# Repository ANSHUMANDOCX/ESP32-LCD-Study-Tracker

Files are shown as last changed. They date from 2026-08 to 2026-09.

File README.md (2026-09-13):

# ESP32-LCD-Study-Tracker
Its a Compact Server based study tracker using a OLED display and a ESP32 that help one track their study/work time on particular subjects and also lets use set a target using the interactive web page hosted on the ESP

# Parts used 
- Esp32 Wroom
- 1602 LCD Display
- PCB with onboard programmer

# Why i made this 
This device is made to solve one of the problems i face while studying i keep on getting distracted while i do something and using this device i will be able to keep track of my productive hours so i can get a reality check on long i think i am productive vs how long i actually am !!. 
# Features
- The system uses Display to set timer and keep track of your productive hours. It also has a webpage hosted on the ESP that helps you check on the hours spent at a glance. Also one can set target for the day how much time one needs to be productive for.
- It also has a Log system that logs the time we have spent on something and helps us keep track of how productive one has been. It also has a option to download the log all together as a csv file.
- There is a header for Connecting the LCD using I2C
- There are 3 Buttons for controlling the Display 'Start' , 'Stop' and , 'Change'.
- We can long press the STOP button to turnoff the backlight of the lcd since it could be distracting for some of us.

# Programming
The code is very simple you will need to import the project in platform io and once flash the system image to load the website on the ESP and next upload the main.c file thats it. Also the subject/ Topic one needs to focus on is under a placeholder so anyone can change it according to their needs.  

# PCB and Schematic and CAD





## Build 
https://youtu.be/7US3xBiMZxA?si=RdkPRtCYgrZsQL8k
https://youtu.be/MXmio46lXlo?si=qvKTUyI2eKW5zzEd




# BOM
| Serial No | Product name | Quantity | Supplier | Price | Total | Link |
| ---: | --- | ---: | --- | ---: | ----: | --- |
| 1 | RC06
03JR-070RL        |      100 | LCSC     | $0.0034 | $0.34 | [LCSC](https://www.lcsc.com/product-detail/C95177.html)   |
|         2 | ME6217C33M5G          |        5 | LCSC     | $0.1219 | $0.61 | [LCSC](https://www.lcsc.com/product-detail/C427602.html)  |
|         3 | CH343P                |        1 | LCSC     | $1.1227 | $1.12 | [LCSC](https://www.lcsc.com/product-detail/C2846043.html) |
|         4 | ESP32-WROOM-32E-N4    |        1 | LCSC     | $3.7668 | $3.77 | [LCSC](https://www.lcsc.com/product-detail/C701341.html)  |
|         5 | TS-1088-AR02016       |       10 | LCSC     | $0.0531 | $0.53 | [LCSC](https://www.lcsc.com/product-detail/C720477.html)  |
|         6 | GT-TC060A-H025-L1S    |        5 | LCSC     | $0.0929 | $0.46 | [LCSC](https://www.lcsc.com/product-detail/C7450623.html) |
|         7 | FRC0603F2201TS        |      100 | LCSC     | $0.0022 | $0.22 | [LCSC](https://www.lcsc.com/product-detail/C2907005.html) |
|         8 | FRC0603F5101TS        |      100 | LCSC     | $0.0021 | $0.21 | [LCSC](https://www.lcsc.com/product-detail/C2907044.html) |
|         9 | RC0603FR-0710KL       |      100 | LCSC     | $0.0040 | $0.40 | [LCSC](https://www.lcsc.com/product-detail/C98220.html)   |
|        10 | CL10B104KB8NNNC       |      200 | LCSC     | $0.0118 | $2.36 | [LCSC](https://www.lcsc.com/product-detail/C1591.html)    |
|        11 | FRC0603F1001TS        |      100 | LCSC     | $0.0029 | $0.29 | [LCSC](https://www.lcsc.com/product-detail/C2907002.html) |
|        12 | SS8050                |       50 | LCSC     | $0.0100 | $0.50 | [LCSC](https://www.lcsc.com/product-detail/C916392.html)  |
|        13 | TYPE-C 16PIN 2MD(073) |       20 | LCSC     | $0.0707 | $1.41 | [LCSC](https://www.lcsc.com/product-detail/C2765186.html) |
|        14 | GRM188R60J476ME15D    |        5 | LCSC     | $0.1934 | $0.97 | [LCSC](https://www.lcsc.com/product-detail/C140782.html)  |
|        15 | CL10A475KP8NNNC       |       50 | LCSC     | $0.0199 | $1.00 | [LCSC](https://www.lcsc.com/product-detail/C1705.html)    |
|        16 | CL10B105KA8NNNC       |       10 | LCSC     | $0.0216 | $0.22 | [LCSC](https://www.lcsc.com/product-detail/C29936.html)   |
|        17 | CL10A106KP8NNNC       |       20 | LCSC     | $0.0353 | $0.71 | [LCSC](https://www.lcsc.com/product-detail/C19702.html)   |
|        18 | PCB       |       1 | JLC     | $2 | $2 | [JLC](jlcpcb.com)   |
|19|LCD Display|1|Robu|$2|$2|[Robu](https://robu.in/product/lcd1602-parallel-lcd-display-with-iic-i2c-interface/)|
||**TOTAL**||||20|||

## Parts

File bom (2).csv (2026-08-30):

Index | LCSC# | MPN | Manufacturer | Package | Customer # | Description | RoHS | Quantity | MOQ | Multiple | Unit Price($) | Extended Price($) | Product Link
1 | C95177 | RC0603JR-070RL | YAGEO | 0603 |  | 100mW 0Ω 75V Thick Film Resistor ±5% 0603 Chip Resistor - Surface Mount RoHS | yes | 100 | 100 | 100 | 0.0034 | 0.34 | https://www.lcsc.com/product-detail/C95177.html
2 | C427602 | ME6217C33M5G | MICRONE | SOT-23-5 |  | 3.3V Positive Fixed SOT-23-5 Voltage Regulators - Linear, Low Drop Out (LDO) Regulators | yes | 5 | 5 | 5 | 0.1219 | 0.61 | https://www.lcsc.com/product-detail/C427602.html
3 | C2846043 | CH343P | WCH | TQFN-16-EP(3x3) |  | USB to UART 6Mbps USB 2.0 TQFN-16-EP(3x3) Interface Controllers | yes | 1 | 1 | 1 | 1.1227 | 1.12 | https://www.lcsc.com/product-detail/C2846043.html
4 | C701341 | ESP32-WROOM-32E-N4 | ESPRESSIF | SMD,25.5x18mm |  | 2.4GHz On-board PCB Antenna -98dBm SMD,25.5x18mm RF Transceiver Modules and Modems RoHS | yes | 1 | 1 | 1 | 3.7668 | 3.77 | https://www.lcsc.com/product-detail/C701341.html
5 | C720477 | TS-1088-AR02016 | XUNPU | SMD,4x3mm |  | Tactile Switch SPST 160gf 2mm SMD (SMT) Tab 4mm x 3mm Surface Mount | yes | 10 | 10 | 10 | 0.0531 | 0.53 | https://www.lcsc.com/product-detail/C720477.html
6 | C7450623 | GT-TC060A-H025-L1S | G-Switch | SMD,6x3mm |  | Tactile Switch SPST 160gf 2.5mm SMD (SMT) Tab 6.05mm x 3.5mm Surface Mount | yes | 5 | 5 | 5 | 0.0929 | 0.46 | https://www.lcsc.com/product-detail/C7450623.html
7 | C2907005 | FRC0603F2201TS | FOJAN | 0603 |  | 2.2kΩ ±1% 100mW 0603 Thick Film Resistor | yes | 100 | 100 | 100 | 0.0022 | 0.22 | https://www.lcsc.com/product-detail/C2907005.html
8 | C2907044 | FRC0603F5101TS | FOJAN | 0603 |  | 5.1kΩ ±1% 100mW 0603 Thick Film Resistor | yes | 100 | 100 | 100 | 0.0021 | 0.21 | https://www.lcsc.com/product-detail/C2907044.html
9 | C98220 | RC0603FR-0710KL | YAGEO | 0603 |  | 100mW 10kΩ 75V Thick Film Resistor ±100ppm/℃ ±1% 0603 Chip Resistor - Surface Mount RoHS | yes | 100 | 100 | 100 | 0.0040 | 0.40 | https://www.lcsc.com/product-detail/C98220.html
10 | C1591 | CL10B104KB8NNNC | Samsung Electro-Mechanics | 0603 |  | 100nF ±10% 50V Ceramic Capacitor X7R 0603 | yes | 200 | 100 | 100 | 0.0118 | 2.36 | https://www.lcsc.com/product-detail/C1591.html
11 | C2907002 | FRC0603F1001TS | FOJAN | 0603 |  | 1kΩ ±1% 100mW 0603 Thick Film Resistor | yes | 100 | 100 | 100 | 0.0029 | 0.29 | https://www.lcsc.com/product-detail/C2907002.html
12 | C916392 | SS8050 | JSMSEMI | SOT-23 |  | Bipolar (BJT) Transistor NPN 25V 1.5A 300mW Surface Mount SOT-23 | yes | 50 | 50 | 50 | 0.0100 | 0.50 | https://www.lcsc.com/product-detail/C916392.html
13 | C2765186 | TYPE-C 16PIN 2MD(073) | SHOU HAN | SMD |  | USB-C (USB TYPE-C) Receptacle Connector 16 Position Surface Mount, Right Angle | yes | 20 | 20 | 20 | 0.0707 | 1.41 | https://www.lcsc.com/product-detail/C2765186.html
14 | C140782 | GRM188R60J476ME15D | muRata | 0603 |  | 47uF ±20% 6.3V Ceramic Capacitor X5R 0603 | yes | 5 | 5 | 5 | 0.1934 | 0.97 | https://www.lcsc.com/product-detail/C140782.html
15 | C1705 | CL10A475KP8NNNC | Samsung Electro-Mechanics | 0603 |  | 4.7uF ±10% 10V Ceramic Capacitor X5R 0603 | yes | 50 | 50 | 50 | 0.0199 | 1.00 | https://www.lcsc.com/product-detail/C1705.html
16 | C29936 | CL10B105KA8NNNC | Samsung Electro-Mechanics | 0603 |  | 1uF ±10% 25V Ceramic Capacitor X7R 0603 | yes | 10 | 10 | 10 | 0.0216 | 0.22 | https://www.lcsc.com/product-detail/C29936.html
17 | C19702 | CL10A106KP8NNNC | Samsung Electro-Mechanics | 0603 |  | 10uF ±10% 10V Ceramic Capacitor X5R 0603 | yes | 20 | 20 | 20 | 0.0353 | 0.71 | https://www.lcsc.com/product-detail/C19702.html

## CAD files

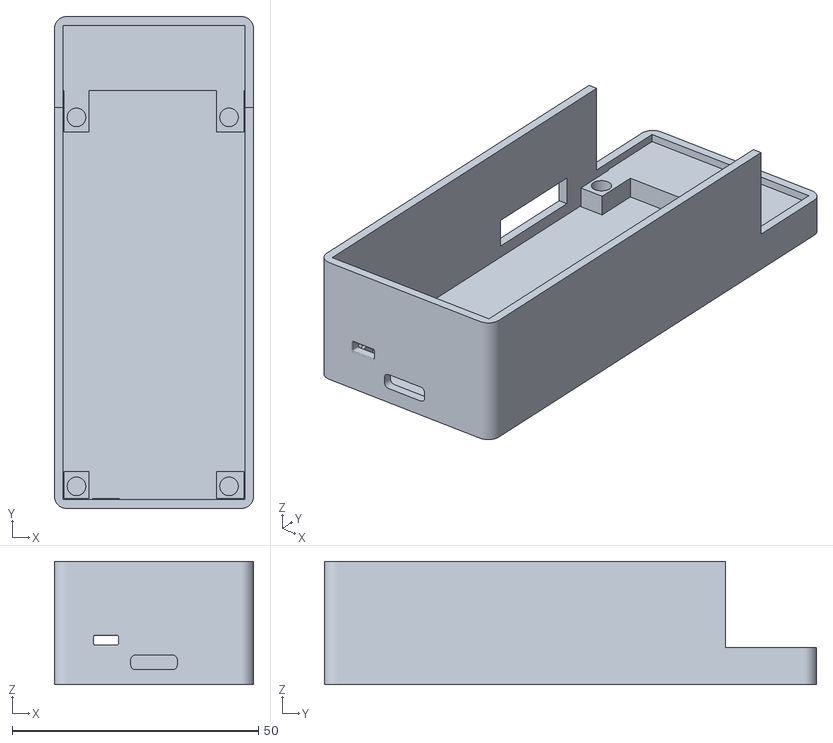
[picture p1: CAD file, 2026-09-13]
CAD/Bottom.stl
40.5 x 100.0 x 25.0

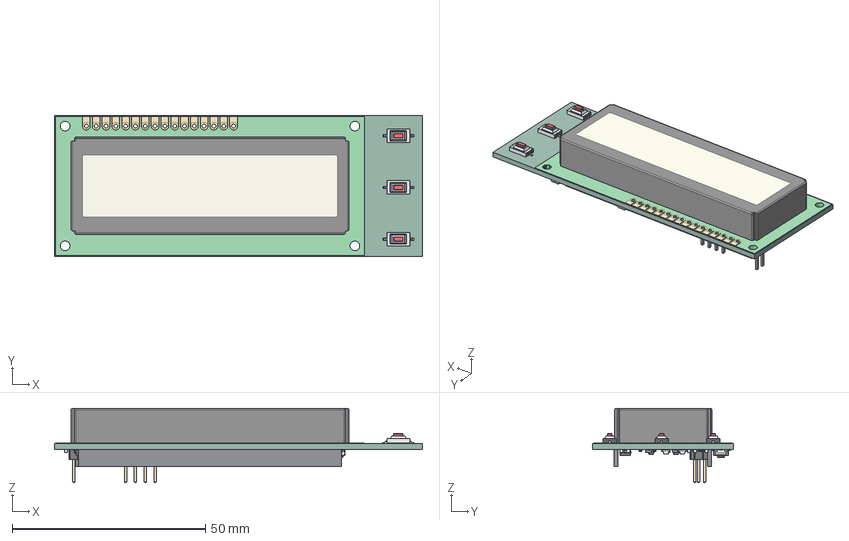
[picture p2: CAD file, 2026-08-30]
PCB/Study_Tracker.step
95.2 x 36.5 x 19.2 mm
SW_SPST_CK_RS282G05A3 x 3
WC1602A
R_0603_1608Metric x 10
PinHeader_1x04_P2.54mm_Vertical
LED_0805_2012Metric x 2
SW_Push_SPST_NO_Alps_SKRK x 2
C_0603_1608Metric x 10
SOT-23 x 2
PinHeader_1x02_P2.54mm_Vertical
SOT-23-5
Stuy Tracker org_PCB

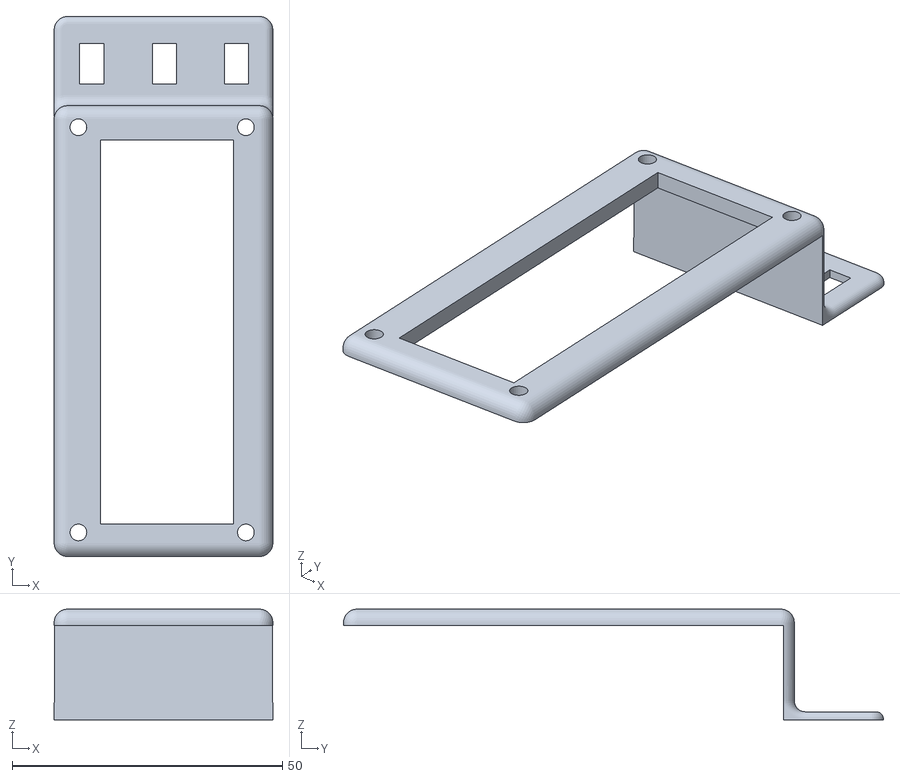
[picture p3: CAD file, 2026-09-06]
CAD/top.stl
40.5 x 100.0 x 20.5

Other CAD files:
CAD/Bottom.f3z
CAD/TOP.f3z

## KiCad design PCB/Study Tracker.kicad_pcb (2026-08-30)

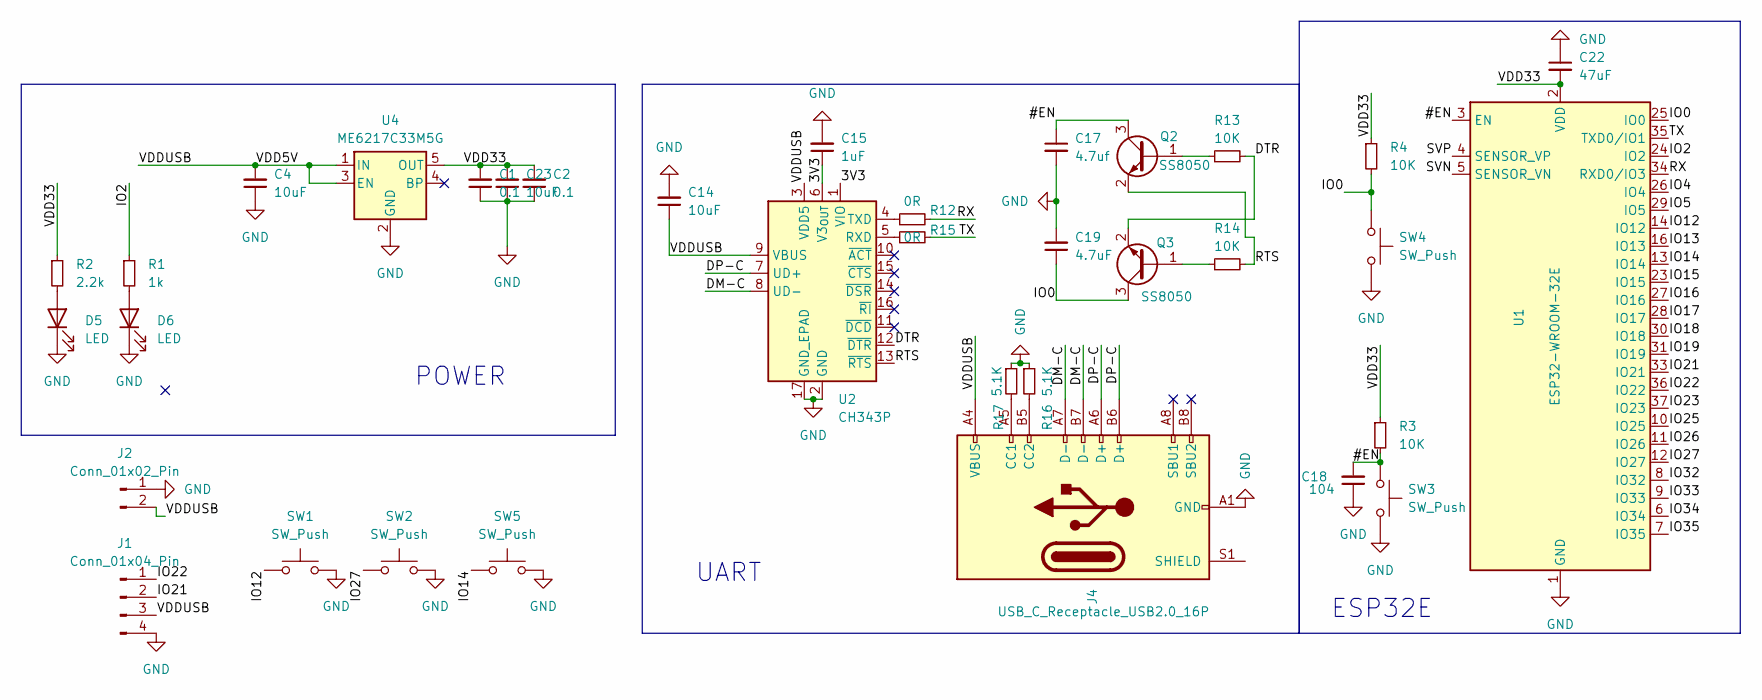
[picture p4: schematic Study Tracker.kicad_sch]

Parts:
C1, C2: 0.1; C_0603_1608Metric_Pad1.08x0.95mm_HandSolder
C4, C14, C23: 10uF; C_0603_1608Metric_Pad1.08x0.95mm_HandSolder
C15: 1uF; C_0603_1608Metric_Pad1.08x0.95mm_HandSolder
C17: 4.7uf; C_0603_1608Metric_Pad1.08x0.95mm_HandSolder
C18: 104; C_0603_1608Metric_Pad1.08x0.95mm_HandSolder
C19: 4.7uF; C_0603_1608Metric_Pad1.08x0.95mm_HandSolder
C22: 47uF; C_0603_1608Metric_Pad1.08x0.95mm_HandSolder
D5, D6: LED; LED_0805_2012Metric_Pad1.15x1.40mm_HandSolder
J1: Conn_01x04_Pin; PinHeader_1x04_P2.54mm_Vertical
J2: Conn_01x02_Pin; PinHeader_1x02_P2.54mm_Vertical
J4: USB_C_Receptacle_USB2.0_16P; USB_C_Receptacle_XKB_U262-16XN-4BVC11
Q2, Q3: SS8050; SOT-23
R1: 1k; R_0603_1608Metric_Pad0.98x0.95mm_HandSolder
R2: 2.2k; R_0603_1608Metric_Pad0.98x0.95mm_HandSolder
R3, R4, R13, R14: 10K; R_0603_1608Metric_Pad0.98x0.95mm_HandSolder
R12, R15: 0R; R_0603_1608Metric_Pad0.98x0.95mm_HandSolder
R16, R17: 5.1K; R_0603_1608Metric_Pad0.98x0.95mm_HandSolder
SW1, SW2, SW5: SW_Push; SW_SPST_CK_RS282G05A3
SW3, SW4: SW_Push; SW_Push_SPST_NO_Alps_SKRK
U1: ESP32-WROOM-32E; ESP32-WROOM-32D
U2: CH343P; WCH_QFN-16-1EP_3x3mm_P0.5mm_EP1.8x1.8mm
U4: ME6217C33M5G; SOT-23-5

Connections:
/3V3: C15.1, U2.1 (VIO), U2.6 (V3_{OUT})
/#EN: C17.1, C18.2, Q2.3 (C), R3.2, SW3.1, U1.3 (EN)
/DM-C: J4.A7 (D-), J4.B7 (D-), U2.8 (UD-)
/DP-C: J4.A6 (D+), J4.B6 (D+), U2.7 (UD+)
/DTR: Q3.2 (E), R13.2, U2.12 (~DTR)
/IO0: C19.1, Q3.3 (C), R4.2, SW4.1, U1.25 (IO0)
/IO2: R1.1, U1.24 (IO2)
/IO4: U1.26 (IO4)
/IO5: U1.29 (IO5)
/IO12: SW1.1, U1.14 (IO12)
/IO13: U1.16 (IO13)
/IO14: SW5.1, U1.13 (IO14)
/IO15: U1.23 (IO15); also elsewhere on the board
/IO16: U1.27 (IO16); also elsewhere on the board
/IO17: U1.28 (IO17); also elsewhere on the board
/IO18: U1.30 (IO18); also elsewhere on the board
/IO19: U1.31 (IO19); also elsewhere on the board
/IO21: J1.2, U1.33 (IO21)
/IO22: J1.1, U1.36 (IO22)
/IO23: U1.37 (IO23); also elsewhere on the board
/IO25: U1.10 (IO25)
/IO26: U1.11 (IO26)
/IO27: SW2.1, U1.12 (IO27)
/IO32: U1.8 (IO32)
/IO33: U1.9 (IO33)
/IO34: U1.6 (IO34)
/IO35: U1.7 (IO35)
/RTS: Q2.2 (E), R14.2, U2.13 (~RTS)
/RX: R12.2, U1.34 (RXD0/IO3)
/SVN: U1.5 (SENSOR_VN)
/SVP: U1.4 (SENSOR_VP)
/TX: R15.2, U1.35 (TXD0/IO1)
/VDD5V: C4.2, C14.1, J1.3, J2.2, J4.A4 (VBUS), J4.A9 (VBUS), J4.B4 (VBUS), J4.B9 (VBUS), U2.3 (VDD5), U2.9 (VBUS), U4.1 (IN), U4.3 (EN); also elsewhere on the board
/VDD33: C1.2, C2.2, C22.2, C23.2, R2.1, R3.1, R4.1, U1.2 (VDD), U4.5 (OUT)
GND: C1.1, C2.1, C4.1, C14.2, C15.2, C17.2, C18.1, C19.2, C22.1, C23.1, D5.1 (K), D6.1 (K), J1.4, J2.1, J4.A1 (GND), J4.A12 (GND), J4.B1 (GND), J4.B12 (GND), R16.1, R17.1, SW1.2, SW2.2, SW3.2, SW4.2, SW5.2, U1.1 (GND), U1.15 (GND), U1.38 (GND), U1.39 (GND), U2.2 (GND), U2.17 (GND_EPAD), U4.2 (GND); also elsewhere on the board
unnamed: D5.2 (A), R2.2
unnamed: D6.2 (A), R1.2
unnamed: J4.A5 (CC1), R17.2
unnamed: J4.B5 (CC2), R16.2
unnamed: Q2.1 (B), R13.1
unnamed: Q3.1 (B), R14.1
unnamed: R15.1, U2.5 (RXD)
unnamed: R12.1, U2.4 (TXD)

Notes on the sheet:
UART
POWER
ESP32E

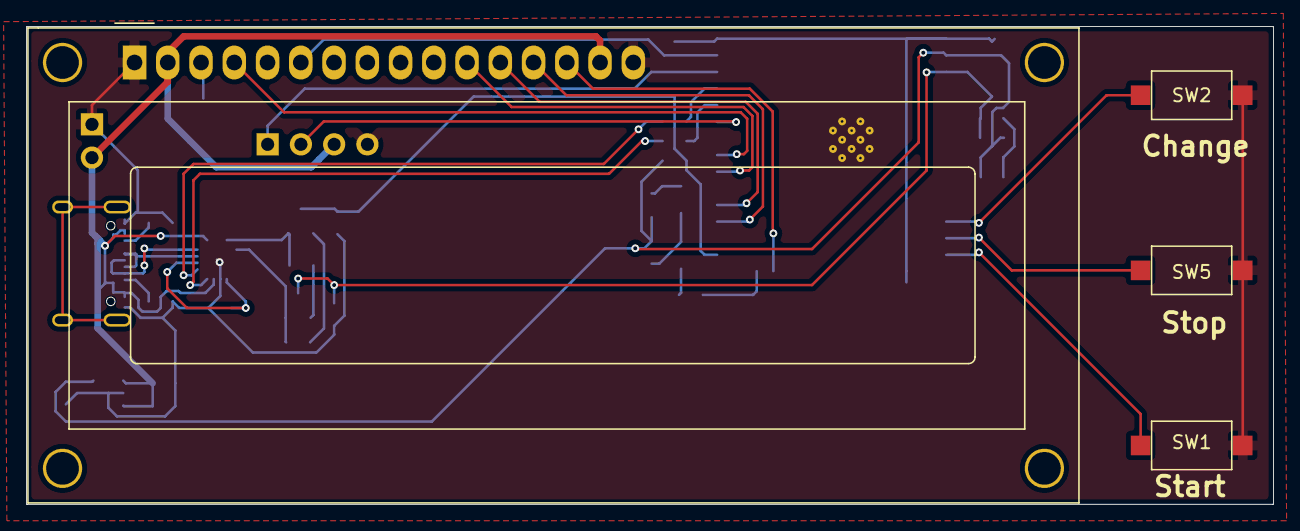
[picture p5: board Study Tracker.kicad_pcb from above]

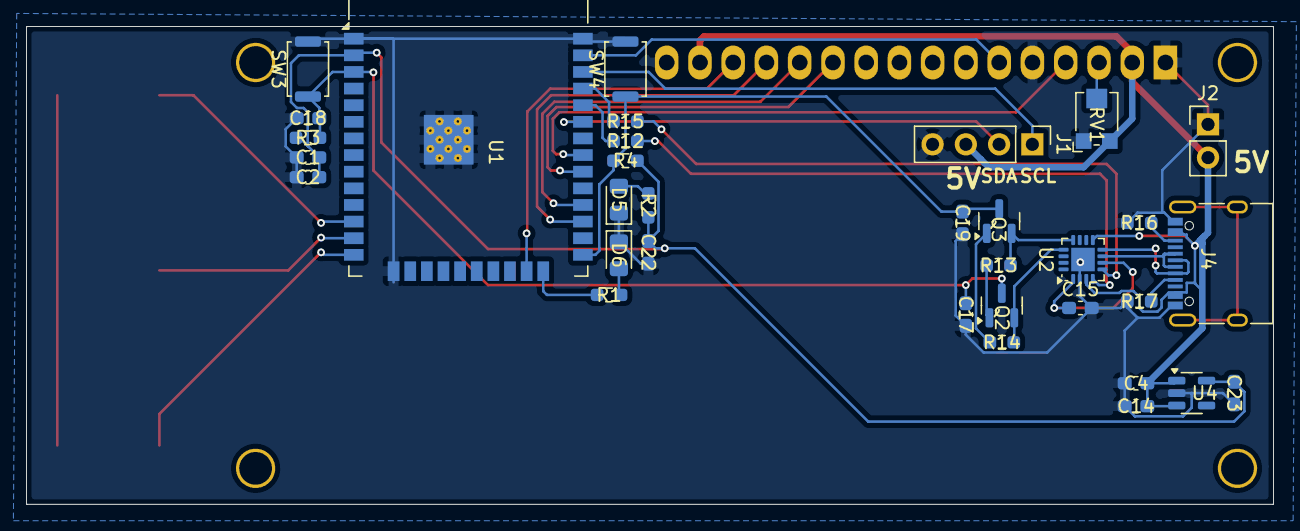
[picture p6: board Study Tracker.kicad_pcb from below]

Board: 2 copper layers, 95.2 x 36.5 mm, 37 parts (33 on the bottom side), 33 nets.

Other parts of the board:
DS1: WC1602A
RV1: R_Potentiometer_Small; Potentiometer_Bourns_TC33X_Vertical

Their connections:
/IO15: DS1.14 (D7); also elsewhere on the board
/IO16: DS1.13 (D6); also elsewhere on the board
/IO17: DS1.12 (D5); also elsewhere on the board
/IO18: DS1.11 (D4); also elsewhere on the board
/IO19: DS1.4 (RS); also elsewhere on the board
/IO23: DS1.6 (E); also elsewhere on the board
/VDD5V: DS1.2 (VDD), DS1.15 (LED(+)), RV1.3; also elsewhere on the board
GND: DS1.1 (VSS), DS1.5 (R/W), DS1.16 (LED(-)), RV1.1; also elsewhere on the board
unnamed: DS1.3 (VO), RV1.2

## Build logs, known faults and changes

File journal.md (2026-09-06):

# ESP32 LCD Study Tracker

Its a Study tracker that helps you be productive while studying along with maintaining a day wise log online on the website hosted on the ESP32 itself

# 2026-09-06: Made an enclosure for the board 

**Total time spent: 2 hours**

Worked on making a enclosure for this device i intentionally lowered the buttons since the buttons i am using are a bit siff and they need some support while being pressed so if i added them to the side or at the top then it would only be a matter of time that they would come out so .. this is what i came up with 



# 2026-07-20: Some problems 

**Total time spent: 0.3 hours**

Found out that the I2c connector for the LCd is no longer working so, i will have to get a new one for the Display 

# 2026-07-19: Looking for More stuff

**Total time spent: 0.3 hours**

Finding the right sized standoffs that i will need to connect the display to the PCB. I am thinking of using 12mm ones since they are big enough to support the whole thing and allowing it to stand upright in the mean time 

# 2026-07-18: organizing the Schematic 

**Total time spent: 0.5 hours**

Made the schematic look more readable by sorting everything in sections for better understanding for everyone.I like making my schematics arranged this way.

# 2026-07-17: Completed Placement and PCB

**Total time spent: 3 hours**

Completed all the placement of the components and the routing also along with 
- added brightness control. Which is a 10k potentiometer connected to the led pin and +5v to control the brightness 
- Also the placement of the buttons is such that if one wants to use it without a case they can.
- Also there is a spare 5v header pin for giving 5v directly and not having to use the type c always and clutter my desk with wires.
- the 5v rails are a bit thicker than normal since 0.2mm is not quite optimal for currents higher than 0.7 amps and considering that the lcd has backlight along with the ESP32 running with wifi on i increased it to 0.5mm
- there is also a debug led onboard for checking if everything thing is in order lol
 

# 2026-07-16: PCB Design 

**Total time spent: 0.5 hours**

Started by arranging the components of the power section first the type c port power regulator and the caps. This the part where all the components need to properly arranged to maximize their efficiency also to suit my purpose like the header pin for 5v in is there to help me connect the 5v from another device i alr have on my desk so i wont need extra cable to connect this .

# 2026-07-15: UART + Power connections

**Total time spent: 1.5 hours**

Wired the onboard programmer along with the voltage regulator and the I2C pins for connecting the LCD to it. 
- I have used the ch343 Onboard programmer for this since i already had this chip on hand and the design is also not very complicated.
-  And for the Voltage regulator i have used the ME6217 3.3v LDO its a very efficient chip and also works very well with the esp32 module this the go to chip i use while designing a esp32 based board.

# 2026-07-15: Schematic Design

**Total time spent: 2 hours**

Since this a Pretty simple project along with it i already have the parts i am going to use to research was not needed except looking at esp32e Wroom module schematic also i will be using a I2c adapter along with the LCD since this simplifies the design along with that i have both of things lying around so ... 


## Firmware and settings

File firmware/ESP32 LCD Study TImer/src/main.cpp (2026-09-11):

#include <Arduino.h>
#include <Wire.h>
#include <LiquidCrystal_I2C.h>
#include <WiFi.h>
#include <WebServer.h>
#include <SPIFFS.h>
#include <Preferences.h>
#include "time.h"

// ---------------- LCD ----------------
LiquidCrystal_I2C lcd(0x27,16,2);

// Buttons
const int scrollButton = 27;
const int startPauseButton = 12;
const int stopButton = 14;

// Subjects
const char* subjects[] = {"Physics","Chem","Maths"};
int subjectIndex = 0;

// Timer vars
bool timerRunning = false;
unsigned long startTime = 0;
unsigned long elapsedTime = 0;
unsigned long totalTime[3] = {0,0,0};

// Backlight state
bool backlightOn = true;
unsigned long backlightTimeout = 5UL * 60UL * 1000UL; // 5 minutes in ms
unsigned long lastActivity = 0;
// Prevent rapid on/off toggles from simultaneous button presses
unsigned long lastBacklightToggle = 0;
const unsigned long backlightToggleDebounce = 500UL; // ms
// Long-press handling for Stop button
unsigned long stopLongPressStart = 0;
bool stopLongPressHandled = false;
const unsigned long stopLongPressMs = 1200UL;

// Preferences for persistence
Preferences prefs;

// ---------------- Wi-Fi / NTP ----------------
const char* ssid = "SSID";
const char* password = "28082005";
IPAddress local_IP(192,168,1,51);
IPAddress gateway(192,168,1,1);
IPAddress subnet(255,255,255,0);
IPAddress primaryDNS(8,8,8,8);
IPAddress secondaryDNS(8,8,4,4);

WebServer server(80);

// NTP
const char* ntpServer = "pool.ntp.org";
const long  gmtOffset_sec = 19800;
const int   daylightOffset_sec = 0;

// ---------------- Debounce Helper ----------------
const unsigned long debounceDelay = 80;   // ms, good value for tact switches

bool buttonPressed(int pin) {
  // store state per pin
  static bool lastState[40];
  static unsigned long lastChange[40];

  bool reading = (digitalRead(pin) == LOW);       // active LOW
  unsigned long now = millis();

  if (reading != lastState[pin] && (now - lastChange[pin] > debounceDelay)) {
    lastChange[pin] = now;
    lastState[pin] = reading;
    if (reading) return true;                     // register only on press
  }
  return false;
}

// ---------------- Helpers ----------------
String formatTime(unsigned long ms) {
  unsigned long sec = ms / 1000;
  unsigned h = sec / 3600;
  unsigned m = (sec % 3600) / 60;
  unsigned s = sec % 60;

  char buf[9];
  sprintf(buf,"%02u:%02u:%02u",h,m,s);
  return String(buf);
}

void showSubjectScreen() {
  lcd.clear();
  lcd.setCursor(0,0);
  lcd.print(subjects[subjectIndex]);
  lcd.setCursor(8,0);
  lcd.print("00:00:00");
  lcd.setCursor(0,1);
  lcd.print("Total");
  lcd.setCursor(8,1);
  lcd.print(formatTime(totalTime[subjectIndex]));
}

void updateSessionTimer() {
  elapsedTime = millis() - startTime;
  lcd.setCursor(8,0);
  lcd.print(formatTime(elapsedTime));
}

void updateTotalTime() {
  lcd.setCursor(8,1);
  lcd.print(formatTime(totalTime[subjectIndex]));
}

// ---------------- Logging ----------------
void saveTotals() {
  prefs.begin("study", false);
  prefs.putULong("phy", totalTime[0]);
  prefs.putULong("chem", totalTime[1]);
  prefs.putULong("math", totalTime[2]);
  prefs.end();
}

void loadTotals() {
  prefs.begin("study", false);
  totalTime[0] = prefs.getULong("phy",0);
  totalTime[1] = prefs.getULong("chem",0);
  totalTime[2] = prefs.getULong("math",0);
  prefs.end();
}

void appendDailyLog() {
  struct tm timeinfo;
  if(!getLocalTime(&timeinfo)) return;

  char datetimeStr[20];
  strftime(datetimeStr,sizeof(datetimeStr),"%Y-%m-%d %H:%M",&timeinfo);

  unsigned long pcm = totalTime[0]+totalTime[1]+totalTime[2];

  File f = SPIFFS.open("/logs.csv","a");
  if(f){
    f.printf("%s,%s,%s,%s,%s\n",
      datetimeStr,
      formatTime(totalTime[0]).c_str(),
      formatTime(totalTime[1]).c_str(),
      formatTime(totalTime[2]).c_str(),
      formatTime(pcm).c_str());
    f.close();
  }

  totalTime[0]=totalTime[1]=totalTime[2]=0;
  saveTotals();
}

// ---------------- Web ----------------
// Removed JSON assembly: this device stores/serves CSV logs directly.
// The web endpoint `/data` now serves the `/logs.csv` file (CSV) instead of building JSON.

// (NEW) Upload helpers
File uploadFile;
String uploadResultMessage = "No upload";

// (NEW) Merge uploaded CSV (append only new datetime rows)
String processUploadedLogs(const char* path) {
  int added = 0, skipped = 0;
  // Collect existing datetimes
  File existing = SPIFFS.open("/logs.csv","r");
  String existingDates = "|";
  if(existing){
    while(existing.available()){
      String line = existing.readStringUntil('\n');
      line.trim();
      if(line.length()==0 || line.startsWith("Date & Time")) continue;
      int c = line.indexOf(',');
      if(c>0){
        existingDates += line.substring(0,c) + "|";
      }
    }
    existing.close();
  }
  File up = SPIFFS.open(path,"r");
  if(!up) return "Upload read error";
  File out = SPIFFS.open("/logs.csv","a");
  if(!out){ up.close(); return "Append open error"; }
  while(up.available()){
    String line = up.readStringUntil('\n');
    line.trim();
    if(line.length()==0 || line.startsWith("Date & Time")) continue;
    int commaCount = 0;
    for(size_t i=0;i<line.length();++i) if(line.charAt(i)==',') commaCount++;
    if(commaCount != 4){ skipped++; continue; }
    int c = line.indexOf(',');
    if(c<=0){ skipped++; continue; }
    String datetime = line.substring(0,c);
    if(existingDates.indexOf("|"+datetime+"|") != -1){
      skipped++; continue;
    }
    out.println(line);
    existingDates += datetime + "|";
    added++;
  }
  up.close();
  out.close();
  char buf[64];
  snprintf(buf,sizeof(buf),"Imported: %d, skipped: %d", added, skipped);
  return String(buf);
}

// ---------------- Setup ----------------
void setup() {
#if defined(ARDUINO_XIAO_ESP32C3)
  Wire.begin(4,5);
#else
  Wire.begin();
#endif
  lcd.init();
  // Start with backlight ON by default
  lcd.backlight();
  backlightOn = true;
  lastActivity = millis();

  pinMode(scrollButton,INPUT_PULLUP);
  pinMode(startPauseButton,INPUT_PULLUP);
  pinMode(stopButton,INPUT_PULLUP);

  Serial.begin(115200);

  if(!SPIFFS.begin(true)) Serial.println("SPIFFS mount failed");

  if(!SPIFFS.exists("/logs.csv") || SPIFFS.open("/logs.csv","r").size()==0){
    File f = SPIFFS.open("/logs.csv","w");
    if(f){
      f.println("Date & Time,Physics,Chemistry,Math,PCM Total");
      f.close();
    }
  }

  loadTotals();

  if(!WiFi.config(local_IP,gateway,subnet,primaryDNS,secondaryDNS))
    Serial.println("Static IP failed");
  WiFi.begin(ssid,password);
  while(WiFi.status()!=WL_CONNECTED){delay(500); Serial.print(".");}
  Serial.println("\nConnected to Wi-Fi");
  configTime(gmtOffset_sec, daylightOffset_sec, ntpServer);

  // ...existing code setting up server. Keep existing routes.
  server.serveStatic("/",SPIFFS,"/index.html");
  server.serveStatic("/script.js",SPIFFS,"/script.js");
  server.serveStatic("/style.css",SPIFFS,"/style.css");
  server.serveStatic("/logs.csv", SPIFFS, "/logs.csv");
  // Serve CSV data directly. The front-end should request /data to get CSV (same as /logs.csv).
  server.serveStatic("/data", SPIFFS, "/logs.csv");
  server.on("/lognow",HTTP_GET,[](){ appendDailyLog(); server.send(200,"text/plain","OK"); });

  server.on("/clearlogs", HTTP_GET, []() {
    if(SPIFFS.exists("/logs.csv")) SPIFFS.remove("/logs.csv");
    File f = SPIFFS.open("/logs.csv", "w");
    if(f){
        f.println("Date & Time,Physics,Chemistry,Math,PCM Total");
        f.close();
    }
    Preferences prefs;
    prefs.begin("study", false);
    prefs.putULong("phy", 0);
    prefs.putULong("chem", 0);
    prefs.putULong("math", 0);
    prefs.end();

    totalTime[0]=totalTime[1]=totalTime[2]=0;
    elapsedTime=0;
    showSubjectScreen();

    server.send(200, "text/plain", "✅ All logs cleared!");
  });

  // (NEW) Upload route (multipart form-data)
  server.on("/uploadlogs", HTTP_POST,
    [](){ server.send(200,"text/plain", uploadResultMessage); },
    [](){
      HTTPUpload &up = server.upload();
      if(up.status == UPLOAD_FILE_START){
        uploadResultMessage = "Processing...";
        if(SPIFFS.exists("/upload_tmp.csv")) SPIFFS.remove("/upload_tmp.csv");
        uploadFile = SPIFFS.open("/upload_tmp.csv","w");
      } else if(up.status == UPLOAD_FILE_WRITE){
        if(uploadFile) uploadFile.write(up.buf, up.currentSize);
      } else if(up.status == UPLOAD_FILE_END){
        if(uploadFile) uploadFile.close();
        uploadResultMessage = processUploadedLogs("/upload_tmp.csv");
        SPIFFS.remove("/upload_tmp.csv");
      } else if(up.status == UPLOAD_FILE_ABORTED){
        if(uploadFile) { uploadFile.close(); SPIFFS.remove("/upload_tmp.csv"); }
        uploadResultMessage = "Upload aborted";
      }
    }
  );

  // Serve target and allow setting it (simple endpoints)
  server.on("/target", HTTP_GET, [](){
    prefs.begin("study", true);
    unsigned long t = prefs.getULong("targ", 0);
    prefs.end();
    String json = "{";
    json += "\"target_secs\":" + String(t) + ",";
    json += "\"target\":\"" + formatTime(t) + "\"";
    json += "}";
    server.send(200, "application/json", json);
  });

  // Simple setter: /settarget?secs=NN
  server.on("/settarget", HTTP_GET, [](){
    if(!server.hasArg("secs")){
      server.send(400, "text/plain", "Missing secs");
      return;
    }
    unsigned long s = (unsigned long) atol(server.arg("secs").c_str());
    prefs.begin("study", false);
    prefs.putULong("targ", s);
    prefs.end();
    server.send(200, "text/plain", "OK");
  });

  // Weekly target endpoints: /weektarget and /setweektarget
  server.on("/weektarget", HTTP_GET, [](){
    prefs.begin("study", true);
    unsigned long t = prefs.getULong("targ_week", 0);
    prefs.end();
    String json = "{";
    json += "\"target_secs\":" + String(t) + ",";
    json += "\"target\":\"" + formatTime(t) + "\"";
    json += "}";
    server.send(200, "application/json", json);
  });

  server.on("/setweektarget", HTTP_GET, [](){
    if(!server.hasArg("secs")){
      server.send(400, "text/plain", "Missing secs");
      return;
    }
    unsigned long s = (unsigned long) atol(server.arg("secs").c_str());
    prefs.begin("study", false);
    prefs.putULong("targ_week", s);
    prefs.end();
    server.send(200, "text/plain", "OK");
  });

  server.begin();
  showSubjectScreen();
}

// ---------------- Loop ----------------
void loop() {
  server.handleClient();

  // Subject scroll (only when timer is not running)
  if (!timerRunning && buttonPressed(scrollButton)) {
    subjectIndex = (subjectIndex + 1) % 3;
    elapsedTime = 0;
    lastActivity = millis();
    showSubjectScreen();
  }

  // Simultaneous Start+Stop -> force backlight off (short-press combo)
  // (removed) simultaneous Start+Stop backlight toggle - not used

  // Start / Pause
  if (buttonPressed(startPauseButton)) {
    lastActivity = millis();
    if (!timerRunning) {
      // starting the timer: ensure backlight is on
      startTime = millis() - elapsedTime;
      timerRunning = true;
      if (!backlightOn) {
        backlightOn = true;
        lcd.backlight();
      }
    } else {
      // pausing the timer: turn backlight off
      // pause timer (do not change backlight on pause)
      elapsedTime = millis() - startTime;
      timerRunning = false;
    }
  }

  // Stop
  // Stop short-press handling (record session time)
  if (buttonPressed(stopButton)) {
    // short press: behave as Stop (record elapsed time)
    if (timerRunning) {
      elapsedTime = millis() - startTime;
      timerRunning = false;
    }
    totalTime[subjectIndex] += elapsedTime;
    elapsedTime = 0;
    saveTotals();
    showSubjectScreen();
  }

  // Long-press Stop -> toggle backlight (handled separately so holding Stop toggles backlight)
  int stopState = digitalRead(stopButton);
  unsigned long now = millis();
  if (stopState == LOW) {
    if (stopLongPressStart == 0) stopLongPressStart = now;
    else if (!stopLongPressHandled && (now - stopLongPressStart >= stopLongPressMs)) {
      if (now - lastBacklightToggle > backlightToggleDebounce) {
        backlightOn = !backlightOn;
        if (backlightOn) lcd.backlight(); else lcd.noBacklight();
        lastBacklightToggle = now;
      }
      stopLongPressHandled = true;
    }
  } else {
    // released
    stopLongPressStart = 0;
    stopLongPressHandled = false;
  }

  // Update LCD
  if (timerRunning) updateSessionTimer();
  updateTotalTime();

  // (removed) auto-turn-off backlight after inactivity - backlight is controlled only by long-press

  // Daily logging at 2 AM
  struct tm timeinfo;
  if(getLocalTime(&timeinfo)){
    static int lastDay=-1;
    if(timeinfo.tm_hour==2 && lastDay!=timeinfo.tm_mday){
      appendDailyLog();
      lastDay=timeinfo.tm_mday;
    }
  }

  delay(5);     // short sleep to avoid busy-loop
}
